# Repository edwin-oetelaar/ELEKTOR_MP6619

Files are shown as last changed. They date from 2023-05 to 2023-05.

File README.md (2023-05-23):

# ELEKTOR_MP6619 Breakout Board Project

This repository contains the KiCAD project files for the Elektor Magazine article about the MP6619 H-bridge chip Breakout Board.

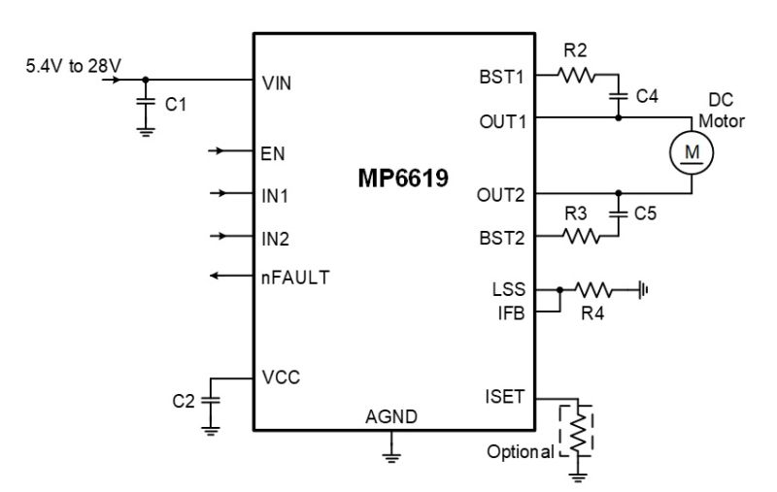
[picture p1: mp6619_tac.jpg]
Minimal board


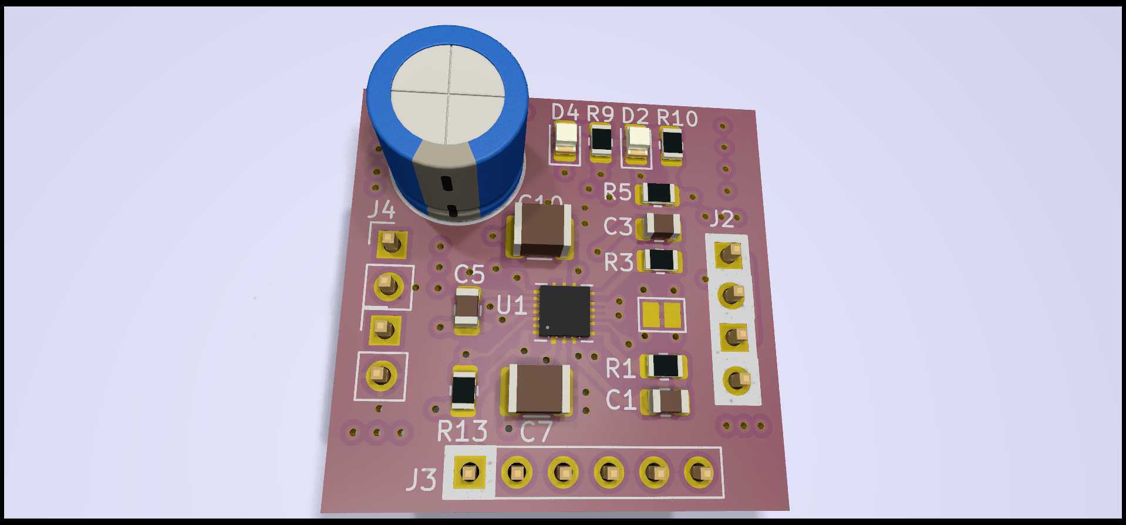
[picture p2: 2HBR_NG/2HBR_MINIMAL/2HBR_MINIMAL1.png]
Minimal Render


## Software Requirement

This project was designed using the latest nightly version of KiCAD. 

### Installation on Ubuntu:

To install the nightly build of KiCAD on Ubuntu, you can use the following commands:

```bash
sudo add-apt-repository ppa:kicad/kicad-dev-nightly
sudo apt update
sudo apt install kicad-nightly
```
### Installation on Windows:
The KiCAD files have also been tested on Windows. To download the nightly builds for Windows, please visit this link. https://downloads.kicad.org/kicad/windows/explore/nightlies

### Project History
The project evolved over time:

* **First Attempt (Dual Chip Breakout Board)**: The initial design of the project was a dual chip breakout board, found in the directory 2HBR_NG.

* **Second Attempt (Single Chip Breakout Board)**: The design was later revised to create a single chip breakout board, found in the directory 2HBR_NG/2HBR_MINIMAL.

To open the project, use the following command in terminal:

```console
user@werkpc:~$ kicad-nightly 2HBR_NG/2HBR_MINIMAL/2HBR_MINIMAL.kicad_pro
```
### Output Files
The 'out1' directory contains the Gerber files used to manufacture the PCB board.

### Support
If you encounter any issues or require further assistance, feel free to create an issue in this repository.

### License
MIT license, no warranties.
The MIT license is a permissive license that is short and easy to understand. It permits users to use, copy, modify, merge, publish, distribute, sublicense, and sell the software and associated documentation files. Here's the general summary:

  * Use: You can use the hardware in any setting, for any purpose, and without needing to pay for it.

  * Copy: You can make as many copies of the hardware as you want, and give them away or sell them.
  * Modify: You can make changes to the hardware, and use the modified hardware. You can also distribute modified copies, or sell hardware based on the modified designs.
  * Merge: You can combine the hardware with other hardware to make something new, and distribute or sell that.
  * Publish: You can share copies of the hardware, or make them publicly available (for example, by posting them online).
  * Distribute: You can give copies of the hardware to other people.
  * Sublicense: You can allow other people to do any of the above with the hardware.
  * Sell: You can sell copies of the hardware.

The above permissions are granted for free, and apply to both the original version of the hardware and to any modified versions that you make.

The license also includes a "disclaimer of warranty" stating that the hardware is provided "as is" without warranty of any kind.

However, please note that any derivative work you create must maintain the original licensing, i.e., the licensing information must always be included in the hardware documentation, design files, etc.

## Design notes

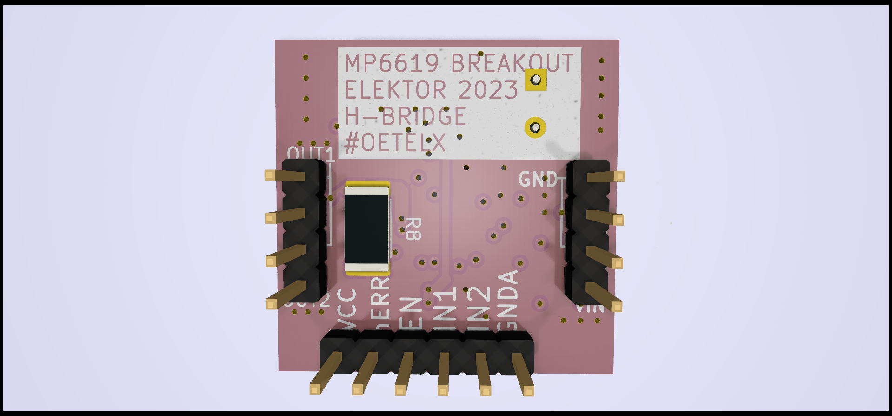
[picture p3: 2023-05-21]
2HBR_NG/2HBR_MINIMAL/2HBR_MINIMAL2.png

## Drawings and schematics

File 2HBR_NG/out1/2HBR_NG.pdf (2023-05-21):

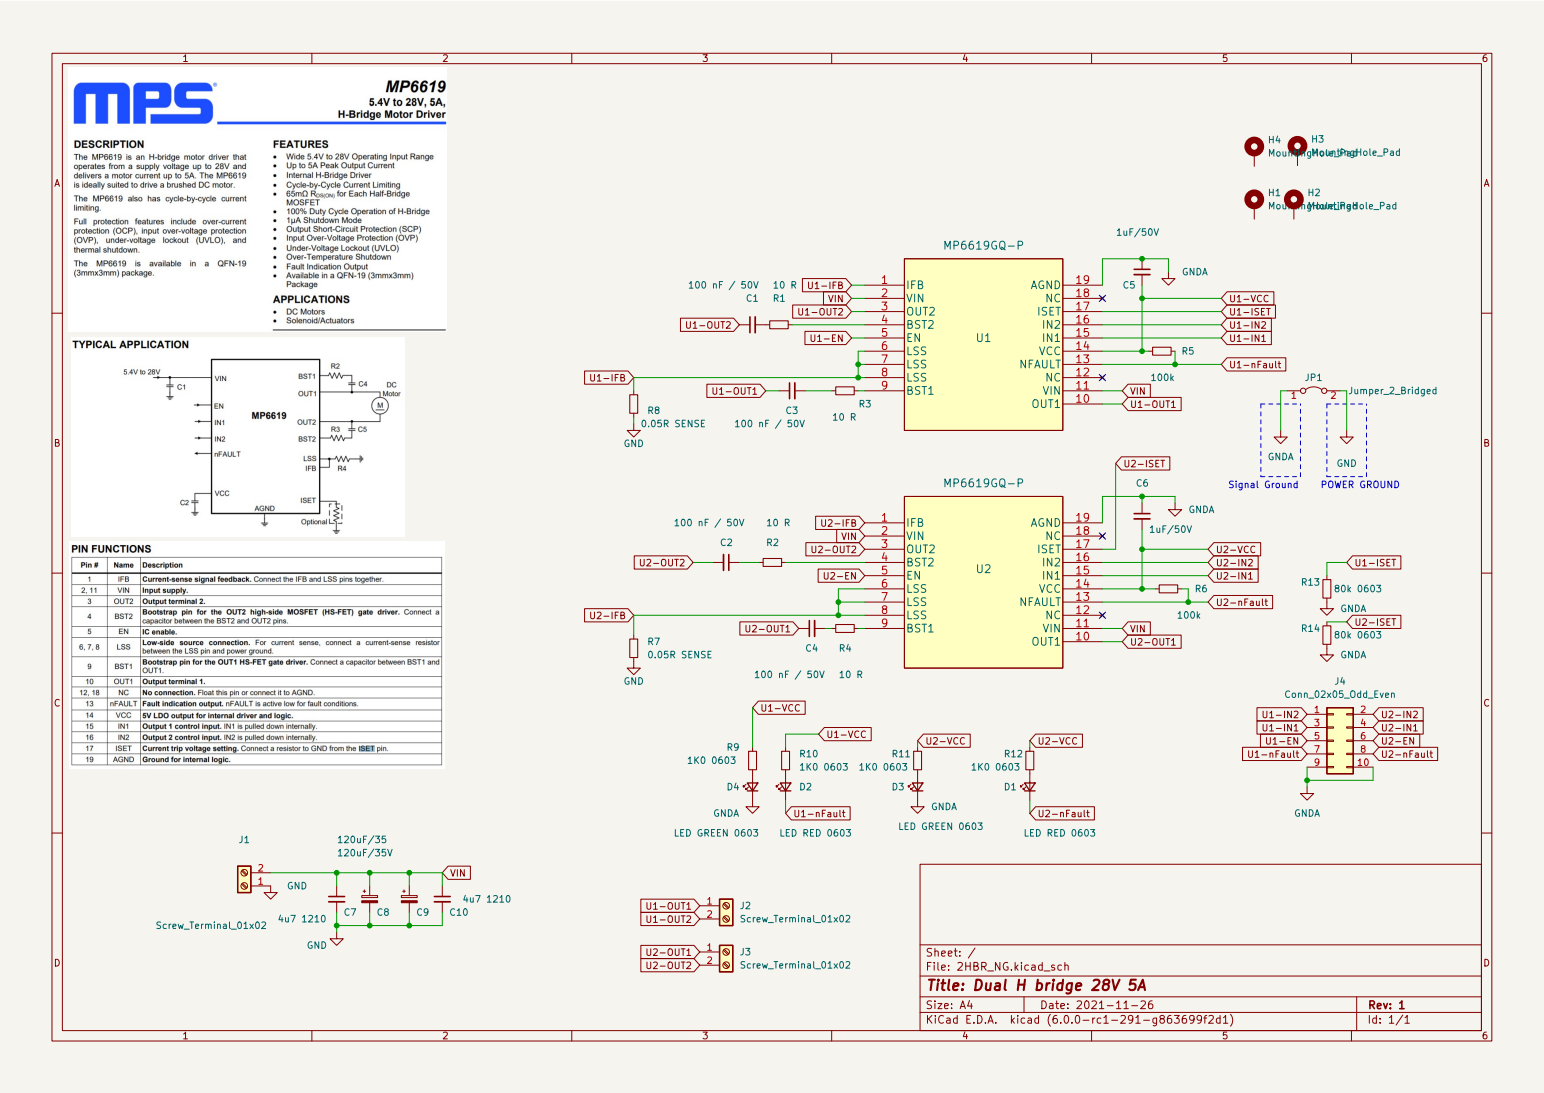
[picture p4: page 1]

File: 2HBR_NG.kicad_sch Sheet: /
Id: 1/1 Title: Dual H bridge 28V 5A

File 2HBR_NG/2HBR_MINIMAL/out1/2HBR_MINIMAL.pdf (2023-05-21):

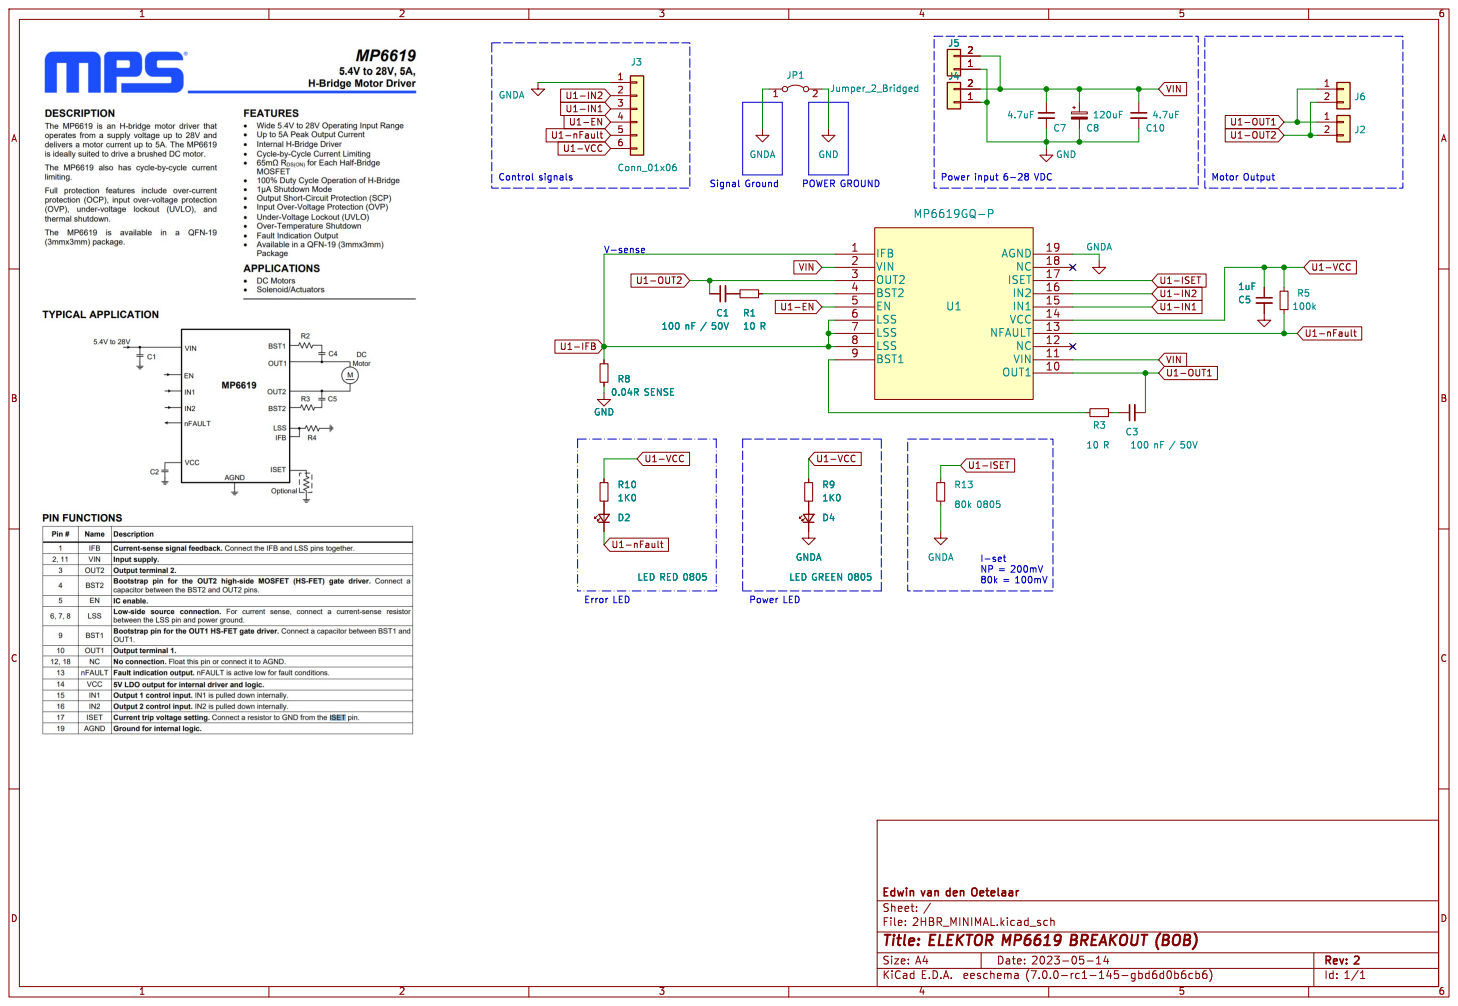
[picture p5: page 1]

File: 2HBR_MINIMAL.kicad_sch Sheet: / Edwin van den Oetelaar R9

Id: 1/1 Title: ELEKTOR MP6619 BREAKOUT (BOB)

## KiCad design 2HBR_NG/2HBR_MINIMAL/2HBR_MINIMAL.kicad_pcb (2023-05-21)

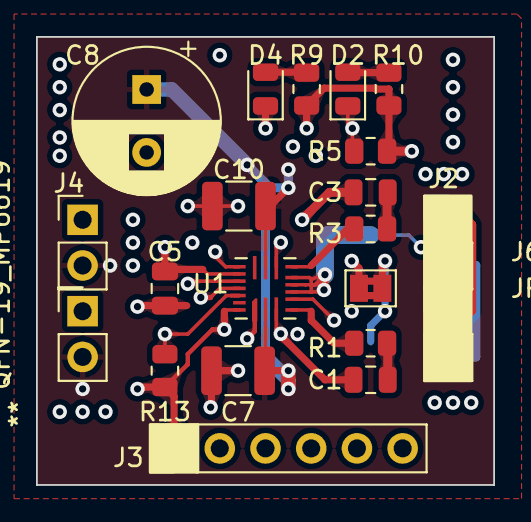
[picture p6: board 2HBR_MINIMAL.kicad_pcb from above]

Board: 4 copper layers, 25.4 x 24.9 mm, 22 parts (1 on the bottom side), 18 nets.

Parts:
C1, C3: 100 nF / 50V; C_0805_2012Metric
C5: 1uF/50V; C_0805_2012Metric
C7, C10: 4u7 1210; C_1210_3225Metric
C8: 120uF/35; CP_Radial_D8.0mm_P3.50mm
D2: LED RED 0805; LED_0805_2012Metric
D4: LED GREEN 0805; LED_0805_2012Metric
J2, J4, J5, J6: Screw_Terminal_01x02; PinHeader_1x02_P2.54mm_Vertical
J3: Conn_01x06; PinHeader_1x06_P2.54mm_Vertical
JP1: Jumper_2_Bridged; SolderJumper-2_P1.3mm_Bridged2Bar_Pad1.0x1.5mm
R1, R3: 10 R; R_0805_2012Metric
R5: 100k; R_0805_2012Metric
R8: 0.05R SENSE; R_2512_6332Metric
R9: 1K0 0603; R_0805_2012Metric
R10: 1K0 0805; R_0805_2012Metric
R13: 80k 0805; R_0805_2012Metric
U1: QFN-19_MP6619; MP6619GQ-P

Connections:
GND: C7.2, C8.2, C10.2, J4.1, J5.1, JP1.2 (B), R8.2
GNDA: C5.1, D4.1 (K), J3.1, JP1.1 (A), R13.2, U1.19 (AGND)
unnamed: C1.2, R1.2
unnamed: C3.1, R3.1
unnamed: D2.2 (A), R10.2
unnamed: D4.2 (A), R9.2
unnamed: R3.2, U1.9 (BST1)
unnamed: R1.1, U1.4 (BST2)
U1-EN: J3.4, U1.5 (EN)
U1-IFB: R8.1, U1.1 (IFB), U1.6 (LSS), U1.7 (LSS), U1.8 (LSS)
U1-IN1: J3.3, U1.15 (IN1)
U1-IN2: J3.2, U1.16 (IN2)
U1-ISET: R13.1, U1.17 (ISET)
U1-OUT1: C3.2, J2.1, J6.1, U1.10 (OUT1)
U1-OUT2: C1.1, J2.2, J6.2, U1.3 (OUT2)
U1-VCC: C5.2, J3.6, R5.1, R9.1, R10.1, U1.14 (VCC)
U1-nFault: D2.1 (K), J3.5, R5.2, U1.13 (NFAULT)
VIN: C7.1, C8.1, C10.1, J4.2, J5.2, U1.2 (VIN), U1.11 (VIN)

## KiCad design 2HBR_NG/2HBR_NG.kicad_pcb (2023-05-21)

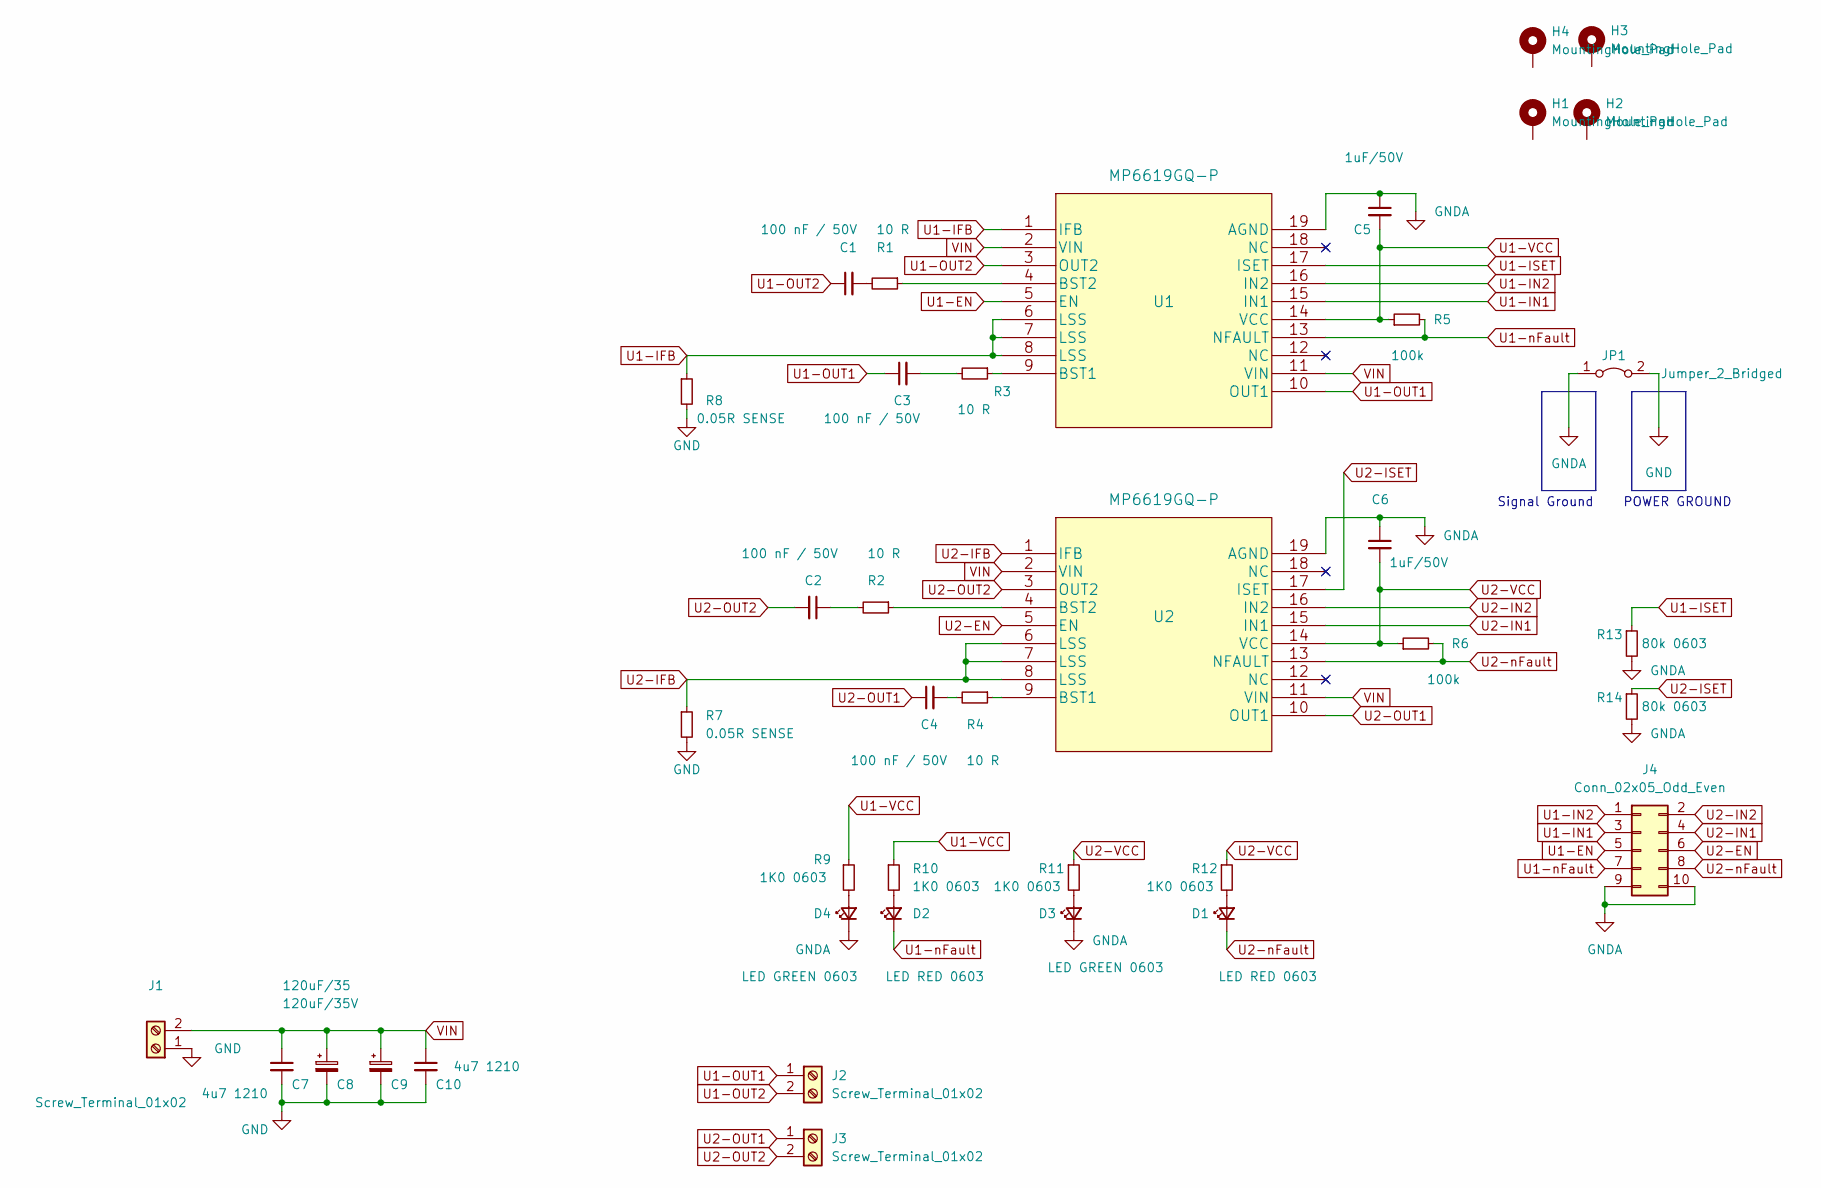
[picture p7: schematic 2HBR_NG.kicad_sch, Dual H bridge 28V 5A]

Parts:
C1, C2, C3, C4: 100 nF / 50V; C_0805_2012Metric; PARTNO MC0805B104K500CT
C5, C6: 1uF/50V; C_0805_2012Metric
C7, C10: 4u7 1210; C_1210_3225Metric
C8: 120uF/35; CP_Radial_D8.0mm_P3.50mm
C9: 120uF/35V; CP_Radial_D8.0mm_P3.50mm
D1, D2: LED RED 0603; LED_0603_1608Metric
D3, D4: LED GREEN 0603; LED_0603_1608Metric
H1, H2, H3, H4: MountingHole_Pad; MountingHole_3mm_Pad_Via
J1, J2, J3: Screw_Terminal_01x02; TerminalBlock_bornier-2_P5.08mm
J4: Conn_02x05_Odd_Even; PinHeader_2x05_P2.54mm_Vertical
JP1: Jumper_2_Bridged; SolderJumper-2_P1.3mm_Bridged2Bar_Pad1.0x1.5mm
R1, R2, R3, R4: 10 R; R_0805_2012Metric
R5, R6: 100k; R_0805_2012Metric; PARTNO CR0805-JW-104ELF
R7, R8: 0.05R SENSE; R_2512_6332Metric; PARTNO RL2512FK-070R05L
R9, R10, R11, R12: 1K0 0603; R_0603_1608Metric
R13, R14: 80k 0603; R_0603_1608Metric
U1, U2: MP6619GQ-P

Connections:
GND: C7.2, C8.2, C9.2, C10.2, J1.1, JP1.2 (B), R7.2, R8.2
GNDA: C5.1, C6.1, D3.1 (K), D4.1 (K), J4.9, J4.10, JP1.1 (A), R13.2, R14.2, U1.19 (AGND), U2.19 (AGND)
unnamed: C3.2, R3.2
unnamed: C4.2, R4.2
unnamed: D1.2 (A), R12.2
unnamed: D2.2 (A), R10.2
unnamed: D3.2 (A), R11.2
unnamed: R1.1, U1.4 (BST2)
unnamed: C1.2, R1.2
unnamed: C2.1, R2.2
unnamed: R3.1, U1.9 (BST1)
unnamed: R4.1, U2.9 (BST1)
unnamed: D4.2 (A), R9.2
unnamed: R2.1, U2.4 (BST2)
U1-EN: J4.5, U1.5 (EN)
U1-IFB: R8.1, U1.1 (IFB), U1.6 (LSS), U1.7 (LSS), U1.8 (LSS)
U1-IN1: J4.3, U1.15 (IN1)
U1-IN2: J4.1, U1.16 (IN2)
U1-ISET: R13.1, U1.17 (ISET)
U1-OUT1: C3.1, J2.1, U1.10 (OUT1)
U1-OUT2: C1.1, J2.2, U1.3 (OUT2)
U1-VCC: C5.2, R5.1, R9.1, R10.1, U1.14 (VCC)
U1-nFault: D2.1 (K), J4.7, R5.2, U1.13 (NFAULT)
U2-EN: J4.6, U2.5 (EN)
U2-IFB: R7.1, U2.1 (IFB), U2.6 (LSS), U2.7 (LSS), U2.8 (LSS)
U2-IN1: J4.4, U2.15 (IN1)
U2-IN2: J4.2, U2.16 (IN2)
U2-ISET: R14.1, U2.17 (ISET)
U2-OUT1: C4.1, J3.1, U2.10 (OUT1)
U2-OUT2: C2.2, J3.2, U2.3 (OUT2)
U2-VCC: C6.2, R6.1, R11.1, R12.1, U2.14 (VCC)
U2-nFault: D1.1 (K), J4.8, R6.2, U2.13 (NFAULT)
VIN: C7.1, C8.1, C9.1, C10.1, J1.2, U1.2 (VIN), U1.11 (VIN), U2.2 (VIN), U2.11 (VIN)

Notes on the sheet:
POWER GROUND
Signal Ground

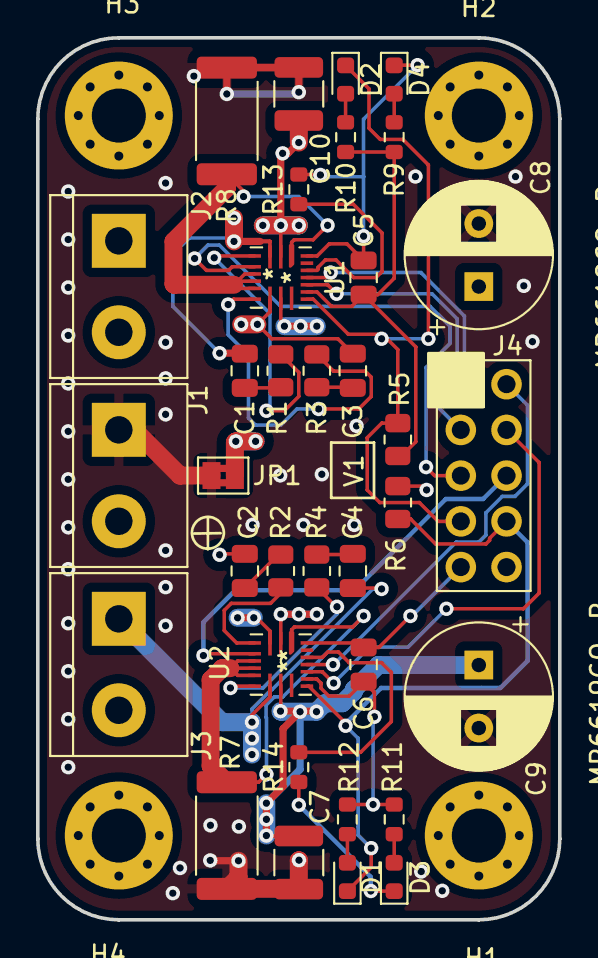
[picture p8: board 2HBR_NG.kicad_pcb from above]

Board: 4 copper layers, 29.0 x 49.0 mm, 39 parts (0 on the bottom side), 33 nets.

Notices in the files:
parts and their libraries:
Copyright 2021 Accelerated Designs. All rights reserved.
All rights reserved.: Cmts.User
